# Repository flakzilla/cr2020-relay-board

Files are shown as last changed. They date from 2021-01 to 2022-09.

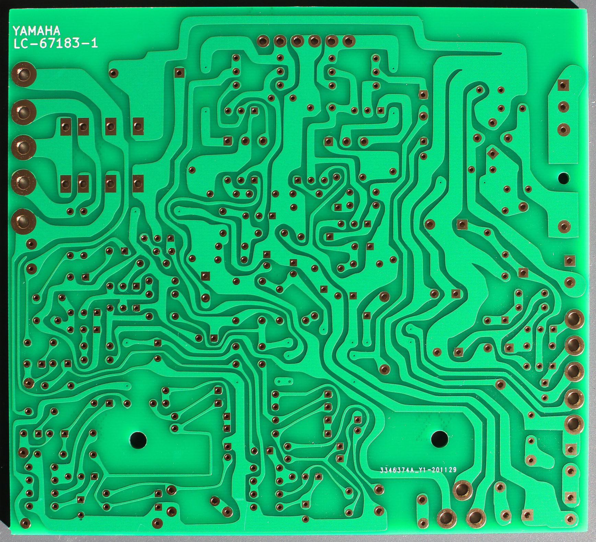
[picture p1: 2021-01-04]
img/board_rear.jpg

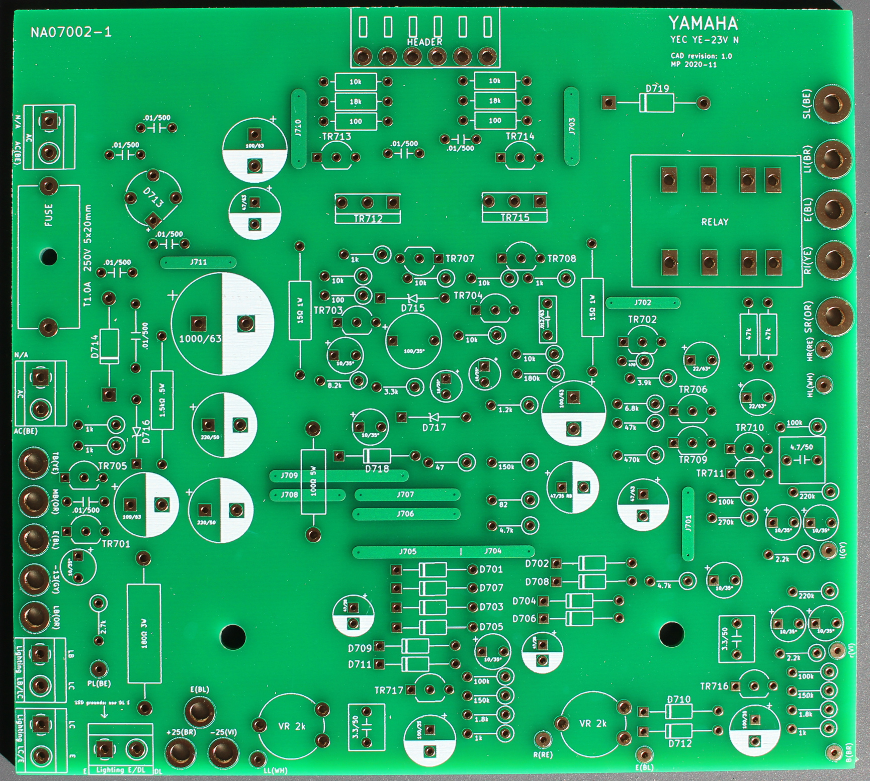
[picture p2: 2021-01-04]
img/board_front.jpg

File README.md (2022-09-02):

# Yamaha CR-2020 relay board LC-67183-1 CAD Reproduction
A modern CAD replica of the LC-67183-1 relay board from the power supply of a Yamaha CR-2020 reciever.

Finished Board

[Front Detail](img/board_front.jpg?raw=true)

[Rear Detail](img/board_rear.jpg?raw=true)

## Summary
This project faithfully recreates the original board based on a sample LC-67183-1 board from a 1976 North American market CR-2020. A complete BOM is provided, including modern part substitutions where original parts may not be available. The KiCAD project files are available for download from this repository ([direct link](https://github.com/flakzilla/cr2020-relay-board/tree/main/CR-2020%20relay%20board%20LC-67183-1)).

The replica doesn't *perfectly* recreate original board - some liberties were taken to make the design more suitable for modern components, and to make some practical changes.

AK user Jayfree also designed a replacement for the relay board, his is a modernized two-layer design instead of a reproduction of the original design. Available here: https://www.audiokarma.org/forums/index.php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 ([Photo](https://www.audiokarma.org/forums/index.php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))

Replica filter capacitor boards have been made as well:
1. [niclasf's board](https://foogadgets.blogspot.com/2020/05/yamaha-cr2020-repair.html) - to get one, contact niclasf on AK, or use his web store at https://www.facebook.com/foogadgets/
1. [jayfree's board](https://www.audiokarma.org/forums/index.php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) - ([Photo](https://www.audiokarma.org/forums/index.php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))

### Caution & Advice
* There are some small differences between model years, but as far as I can tell, this board should work for any model year. **Check your CR-2020's power supply carefully** before trying to use this reproduction board.
* At least 2oz copper is required for the PCB.
* The board's silkscreen includes very small text which isn't always clearly readable. A PDF export of the silkscreen markings is included for reference.
* Read this thread first: https://www.audiokarma.org/forums/index.php?threads/cad-new-yamaha-cr-2020-capacitor-board.912553/

### Reference information for working on a CR-2020
A collection of reference information useful for working on the CR-2020 is included in this repo. The collection contains:
* Recap BOMs for all CR-2020 PCBs
* Broken-out PCB diagrams with some corrections made for misprints and errors in the original diagrams
* Datasheets for many of the original transistors and diodes
* Service Manual and power supply service bulletins
* High resolution copies of the block diagram, schematic diagram, and wiring diagram

Most of this information can be found on the Internet already, but hopefully this collection will save time for those working on a CR-2020.

https://github.com/flakzilla/cr2020-relay-board/tree/main/CR-2020%20reference%20information

### Acknowledgements
The author would like to thank AudioKarma users avionic, niclasf, and jayfree. Owe each of you a beer or 3. :)

## How-To
### PCB
Recommend JLCPCB: https://jlcpcb.com/.

Prepared gerber files for this board: [Gerbers, v1.0](https://github.com/flakzilla/cr2020-relay-board/raw/main/CR-2020%20relay%20board%20LC-67183-1/gerber%20zips/CR2020%20relay%20board%20LC-67183-1%20v1.0.zip)

Board requires 1.6mm PCB thickness and **2oz copper weight**. Thicker copper is mandatory due to high current passing through the relay.

### Parts
BOM:
* [ODS Format](https://github.com/flakzilla/cr2020-relay-board/raw/main/CR-2020%20relay%20board%20LC-67183-1/BOM/BOM.ods)
* [Excel Format](https://github.com/flakzilla/cr2020-relay-board/raw/main/CR-2020%20relay%20board%20LC-67183-1/BOM/BOM.xlsx)

Carefully read and understand the notes in the BOM sheet, and check everything against your own CR-2020. Plan to recover and reuse the factory TO-92 transistors. Note that this BOM is not compatible with Jayfree's modernized relay board (see the Summary section above).

### Assembly
Reference materials:
* [Board diagram](https://github.com/flakzilla/cr2020-relay-board/blob/main/CR-2020%20relay%20board%20LC-67183-1/reference/power%20supply%20c%20board%20diagram_fixed.png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) from the service manual, typos and mistakes present in the original diagram have been fixed
* [PDF of PCB markings](https://github.com/flakzilla/cr2020-relay-board/blob/main/CR-2020%20relay%20board%20LC-67183-1/reference/markings%20diagram%20v1.0.pdf) since the silkscreen text on the board might be too small to read clearly
* [Some examples of TO-220 heatsinks](https://github.com/flakzilla/cr2020-relay-board/tree/main/CR-2020%20relay%20board%20LC-67183-1/reference/TO-220%20heatsink) that can be used for TR712/715

## License
This project is released under the terms of the Creative Commons Attribution + Noncommercial + ShareAlike (BY-NC-SA) license. https://creativecommons.org/licenses/by-nc-sa/2.0/

This project is distributed 'as-is' in the hope that it will be useful, but WITHOUT ANY WARRANTY; without even the implied warranty of MERCHANTABILITY or FITNESS FOR A PARTICULAR PURPOSE.

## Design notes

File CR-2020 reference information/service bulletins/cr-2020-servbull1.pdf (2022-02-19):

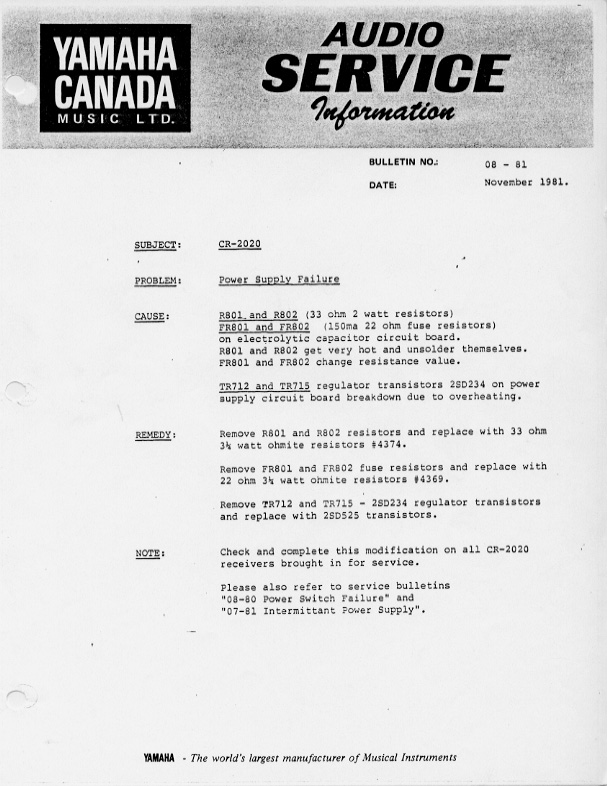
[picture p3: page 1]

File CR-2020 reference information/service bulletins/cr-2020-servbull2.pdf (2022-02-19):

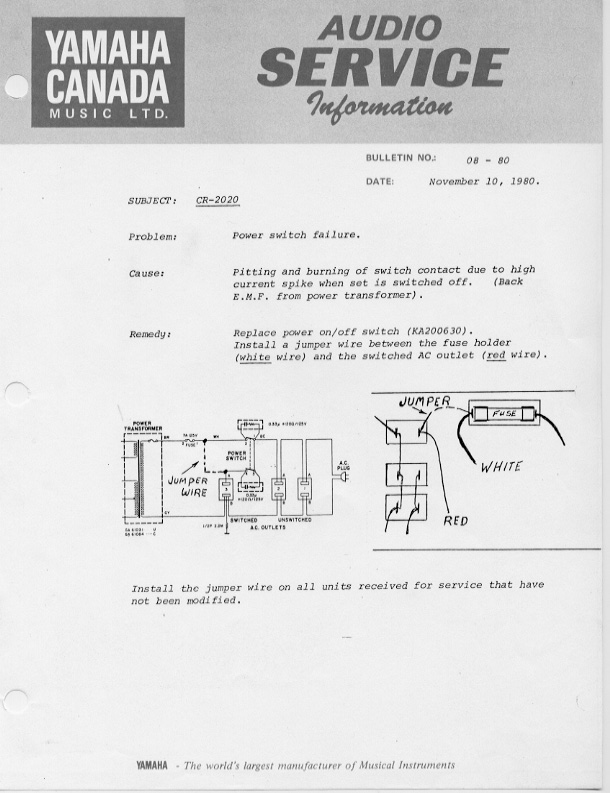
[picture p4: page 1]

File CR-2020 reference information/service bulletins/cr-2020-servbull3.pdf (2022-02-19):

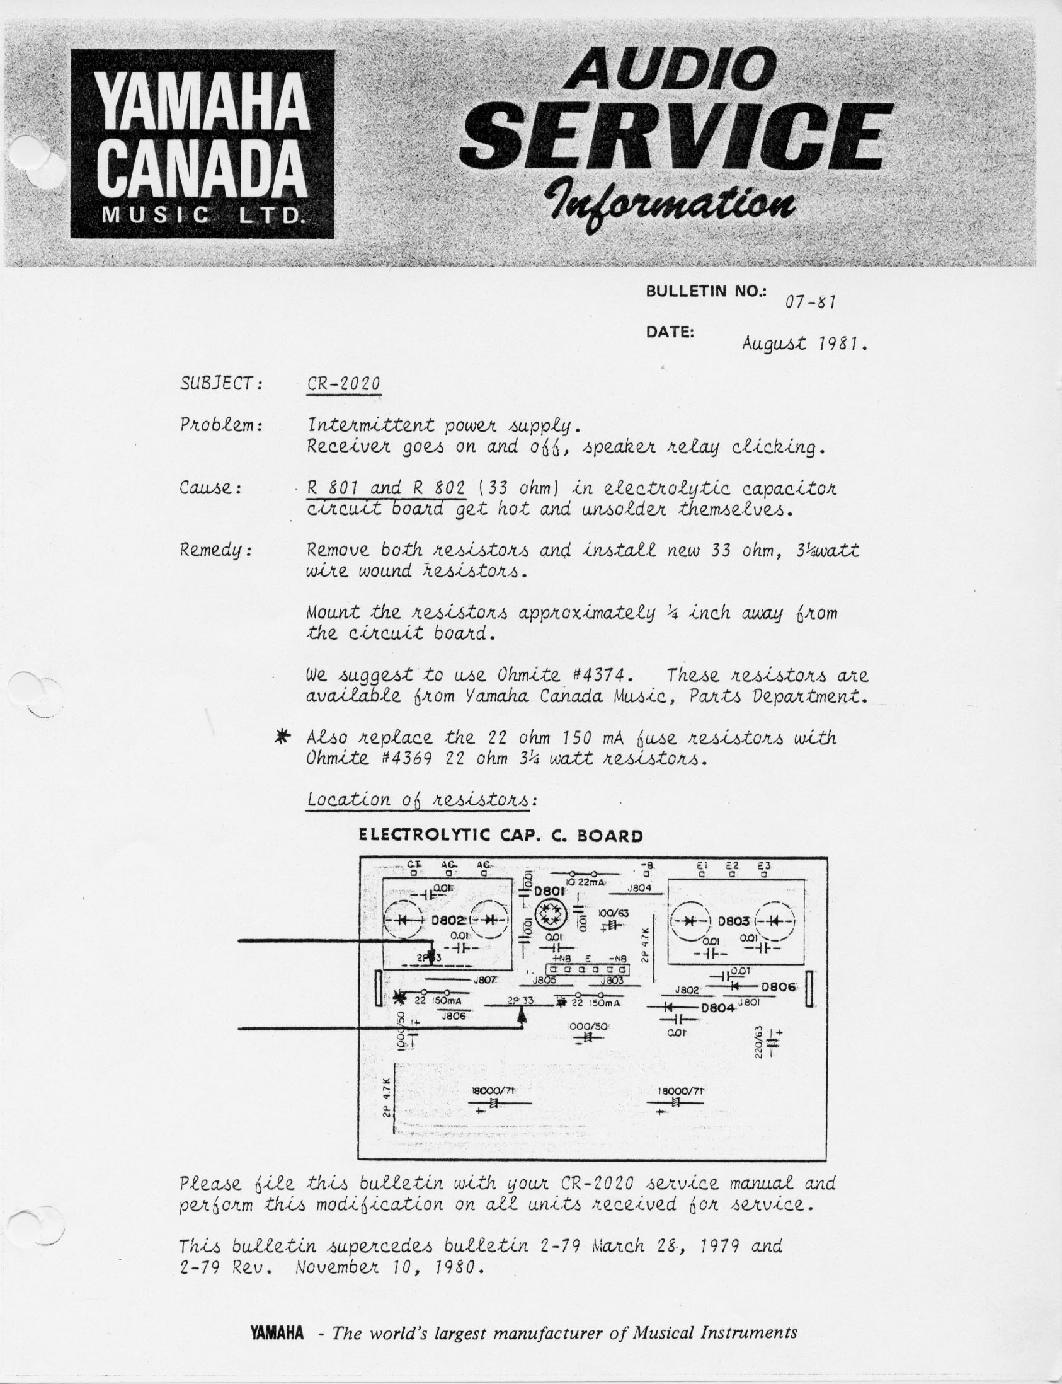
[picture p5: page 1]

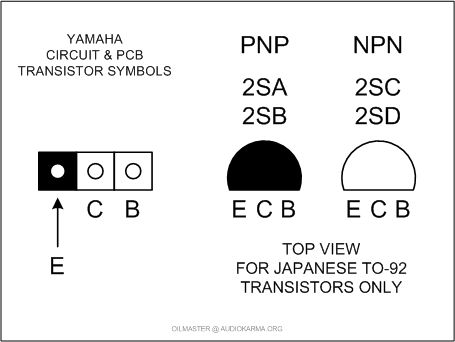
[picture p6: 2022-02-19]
CR-2020 reference information/misc/Yamaha Transistor Symbols.jpg

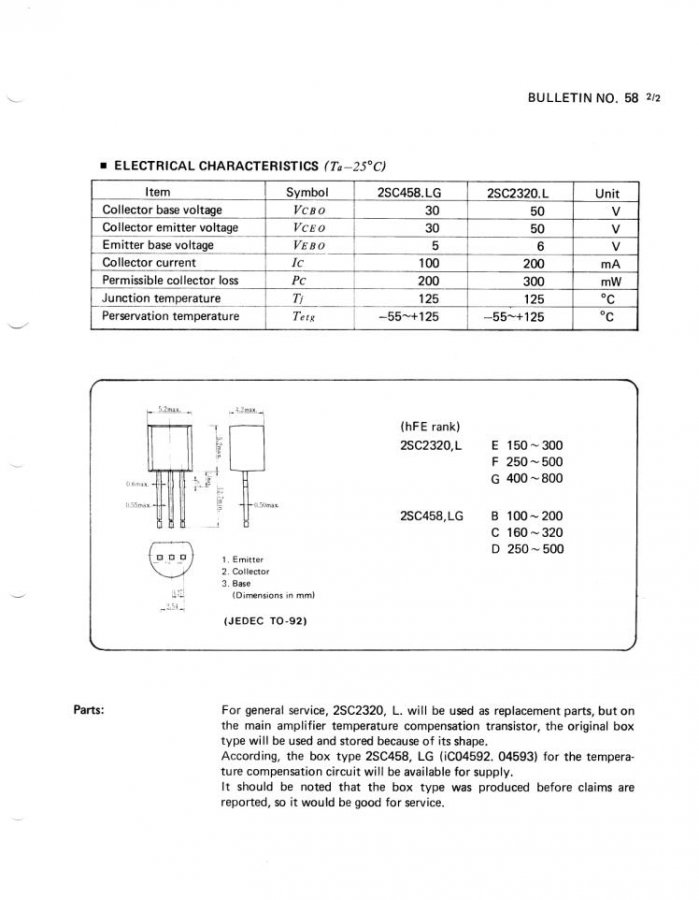
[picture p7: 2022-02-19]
CR-2020 reference information/service bulletins/2SC458-page-02_2.JPG

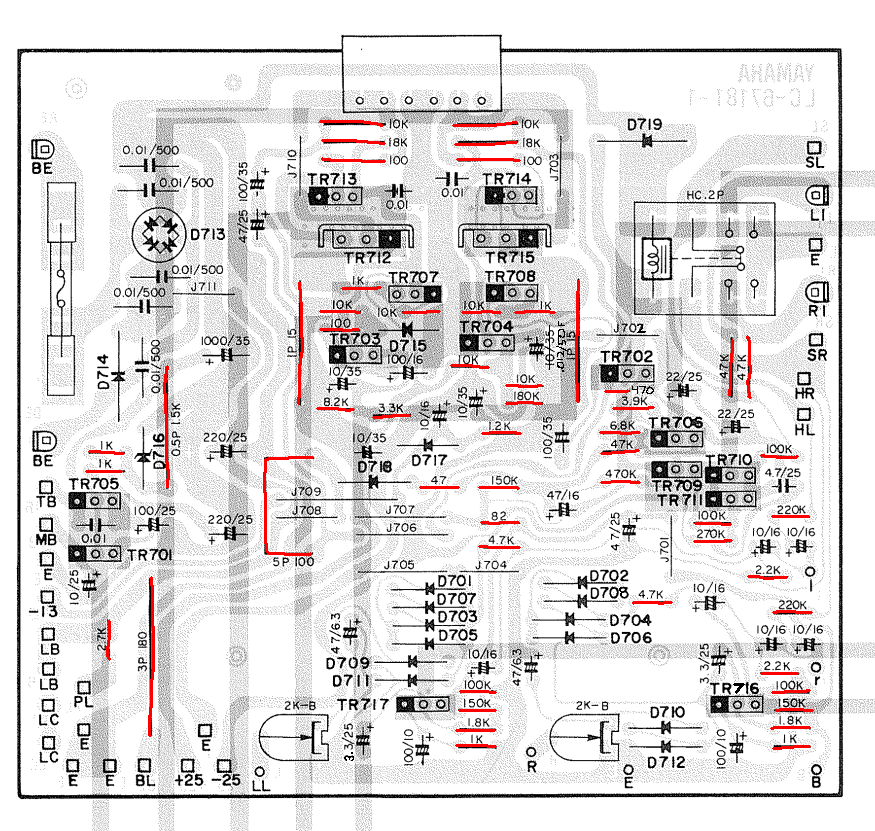
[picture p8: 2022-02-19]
CR-2020 reference information/board diagrams/power supply c board resistor map.png

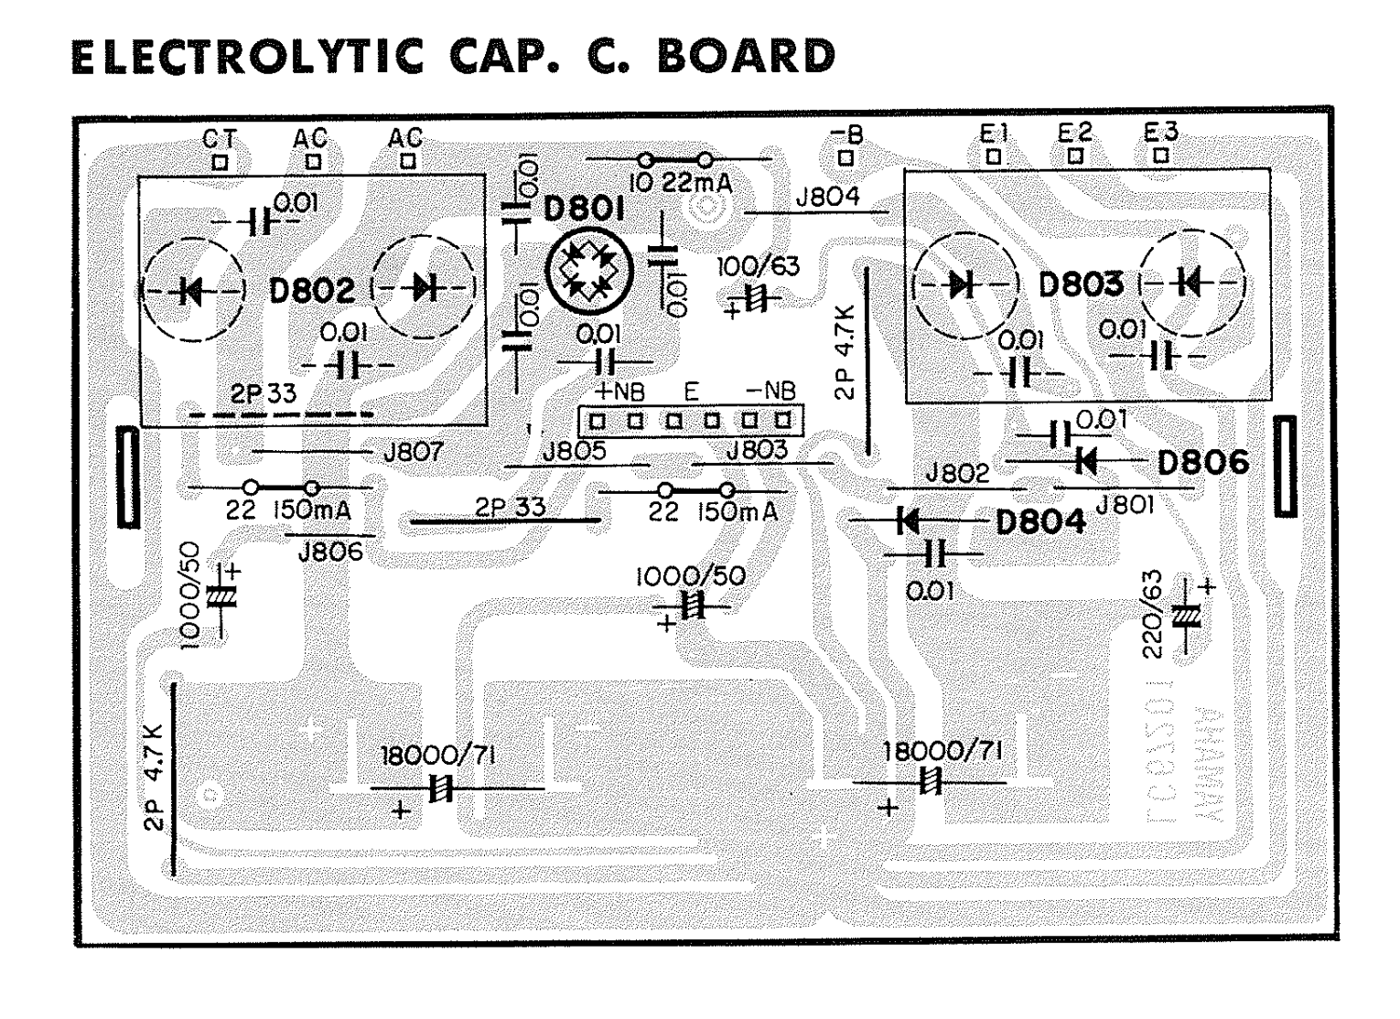
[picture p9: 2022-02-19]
CR-2020 reference information/board diagrams/electrolytic cap c board diagram.png

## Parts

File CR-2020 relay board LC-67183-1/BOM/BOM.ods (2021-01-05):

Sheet: Transistors
Transistor ID | Orig Part | Modern Sub | Remark
TR701 | 2SD400 (E) | KSC2383 (O)
TR702 | 2SB544 (E) | KSA1013 (Y)
TR703 | 2SD667 (C) | KSC2383Y or KSC2690AY | 2SD667 was installed in my 2020, service manual calls for 2SC1890. YMMV
TR704 | 2SA844 (E) | KSA1015 (Y)
TR705 | 2SD400 (E) | KSC2383 (O)
TR706 | 2SC1918 | KSC1845 | Orig part outperforms modern sub. Decent alternative is 2SC2240, if you can get one
TR707 | 2SC1213A | KSC2383 (O)
TR708 | 2SA673A | KSA1013 (Y)
TR709 | 2SC1918 | KSC1845 | Orig part outperforms modern sub. Decent alternative is 2SC2240, if you can get one
TR710 | 2SC1918 | KSC1845 | Orig part outperforms modern sub. Decent alternative is 2SC2240, if you can get one
TR711 | 2SA844 | KSA1015 (Y)
TR712 | 2SD525 | TIP41C | Original part 2SD234, service bulletin upgrades to 2SD525. If original 2SD234 is installed, replace with modern part.
TR713 | 2SD667 (C) | KSC2383Y or KSC2690AY | 2SD667 was installed in my 2020, service manual calls for 2SC1890. YMMV
TR714 | 2SA844 (E) | KSA1015 (Y)
TR715 | 2SD525 | TIP41C | Original part 2SD234, service bulletin upgrades to 2SD525. If original 2SD234 is installed, replace with modern part.
TR716 | 2SC1918 | KSC1845 | Mislabeled as “TR718” in the circuit diagram and as “TR416” on the board diagram. Orig part outperforms modern sub. Decent alternative is 2SC2240, if you can get one
TR717 | 2SC1918 | KSC1845 | Orig part outperforms modern sub. Decent alternative is 2SC2240, if you can get one

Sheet: Capacitors
Capacitor Type | uF | V | Dia | Lead spacing | Qty | Modern replacement | Remark
Ceramic disc | 0.01 | 630 | 5mm | 5mm (and one 10mm) | 8 | TDK FA26C0G2J103JNU06 | Modern repl is MLCC type with C0G dielectric
Film | 3.3 | 50 | 7.2x5.5 | 5mm | 2 | MKS2B043301H00JSSD | Original low-uF electrolytic replaced with film
Film | 4.7 | 50 | 7.2x5.5 | 5mm | 1 | MKS2B044701K00JSSD | Original low-uF electrolytic replaced with film
Film | 0.012 | 63 | 7.2x2.5 | 5mm | 1 | MMK5123J63J01L16.5TA18 | This is the factory sub part between TR704 and TR702
Electrolytic (RB type) | 47 | 35 | 8mm | 3.5mm | 1 | UKL1V470KPDANA | This is the “RB Type” 47/16 capacitor above D702, replace with low leakage type
Electrolytic | 100 | 63 | 10mm | 5mm | 3 | UPW1J101MPD
Electrolytic | 47 | 63 | 8mm | 3.5mm | 2 | UPW1J470MPD
Electrolytic | 1000 | 63 | 16mm | 7.5mm | 1 | UPW1J102MHD
Electrolytic | 220 | 50 | 10mm | 5mm | 2 | UPW1H221MPD
Electrolytic | 10 | 35 | 5mm | 2mm | 11 | UPW1V100MDD | Footprint may be deliberately enlarged for better pad placement – marked with *
Electrolytic | 100 | 35 | 8mm | 3.5mm | 3 | UPW1V101MPD | Footprint may be deliberately enlarged for better pad placement – marked with *
Electrolytic | 47 | 35 | 6.3mm | 2.5mm | 2 | UPW1V470MED
Electrolytic | 22 | 63 | 6.3mm | 2.5mm | 2 | UPW1J220MED | Footprint may be deliberately enlarged for better pad placement – marked with *

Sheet: Diodes
Diode ID | Type | Qty | Lead spacing | Orig. Spec | Modern replacement | Modern replacement (alt) | Remark
D701-712,718 | Diode DO-35 | 13 | Variable | 1S1555 | 1N4148
D714 | Diode DO-41 | 1 | Variable | 1S1885 | 1N4002G
D715 | Zener DO-35 | 1 | Variable | HZ78 | TZX6V8D
D716-717 | Zener DO-35 | 2 | Variable | HZ12C | NZX14A,133
D719 | Diode DO-41 | 1 | Variable | 1S1886 | 1N4004G |  | 1S1886 was installed in my CR, service manual calls for 1S1555. YMMV
D713 | Bridge Rectifier WOM-4 | 1 | 5mm | 1D4B1 (1.5A / 200v) | Rectron W04M | Vishay B250C1500G-E4/51 | Rectron part is EOL, but may still be available

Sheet: Resistors
Type | Resistance | Power | Qty | Modern replacement | Modern replacement (alt) | Resistance of new part (if different from original) | Remark
Power (WW) | 15 | 1 | 2 | Vishay RS01A15R00FB12
Power (WW) | 180 | 3 | 1 | Vishay RS02B180R0FE12
Power (WW) | 100 | 5 | 1 | Ohmite WHE100FET | Vishay RS005100R0FB12 |  | Pad spacing is narrow for a 5W WW resistor. Ohmite part is 5mm shorter and is easier to fit, but either works. Leads must be formed to make a standoff
Power (MOX) | 1.5k | 0.5 | 1 | CMF601K5000BEBF
MOX | 10k | 0.25 | 7 | CMF5510K000FKEB
MOX | 18k | 0.25 | 2 | CMF5518K200FKEK |  | 18.2k
MOX | 100 | 0.25 | 3 | CMF55100R00FHEK
MOX | 47k | 0.25 | 3 | CMF5547K000FHEK
MOX | 1k | 0.25 | 4 | CMF551K0000FHEB
MOX | 1k | 0.25 | 2 | CMF501K0000FHEB |  |  | Use these two for the two groups of 4 near the front, .25W part can sit flush with board
MOX | 2.7k | 0.25 | 1 | CMF552K7000FKR6
MOX | 100k | 0.25 | 2 | CMF55100K00FHEA
MOX | 100k | 0.25 | 2 | CMF50100K00FHEB |  |  | Use these two for the two groups of 4 near the front, .25W part can sit flush with board
MOX | 150k | 0.25 | 1 | CMF55150K00FKEA
MOX | 150k | 0.25 | 2 | CMF50150K00FHEB |  |  | Use these two for the two groups of 4 near the front, .25W part can sit flush with board
MOX | 1.8k | 0.25 | 2 | CMF501K8200FHEB |  | 1.82k | Use these two for the two groups of 4 near the front, .25W part can sit flush with board
MOX | 2.2k | 0.25 | 2 | CMF552K2000FKEK
MOX | 220k | 0.25 | 2 | CMF55221K00FHEK |  | 221k
MOX | 4.7k | 0.25 | 2 | CMF554K7000FHEK
MOX | 270k | 0.25 | 1 | CMF55274K00FHEB |  | 274k
MOX | 470 | 0.25 | 1 | CMF55470R00FKR6
MOX | 3.9k | 0.25 | 1 | CMF553K9000FKBF
MOX | 6.8k | 0.25 | 1 | CMF556K8000FKEB
MOX | 470k | 0.25 | 1 | CMF55475K00FHEA |  | 475k
MOX | 47 | 0.25 | 1 | CMF5547R000FEEK
MOX | 82 | 0.25 | 1 | H882RFZA
MOX | 180k | 0.25 | 1 | CMF55182K00FKEK |  | 182k
MOX | 1.2k | 0.25 | 1 | CMF551K2000FKR6
MOX | 8.2k | 0.25 | 1 | CMF558K2500FKEK |  | 8.25k
MOX | 3.3k | 0.25 | 1 | CMF553K3200FHEB |  | 3.32k
Trim pot | 2k | ?? | 2 | PT10LV10-202A2020-PM-S |  |  | Thanks jayfree :)

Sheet: Misc
Part | Orig. Spec | Qty | Modern replacement | Remark
Fuse holder | 6x30mm type fuse holder | 1 | Schurter 0031.8201
Fuse | 6x30mm 1A 250V fast blow | 1 | Littelfuse 0217001.MXP | Any standard 5x20mm 1A fast-blow fuse will work fine
Protection relay | Panasonic HC2-HP-DC12V-F | 1 | Omron MY2-02-DC12 | Orig part has wider mounting pins (1.5mm)
6-pin header |  | 1 | Molex 09-48-3065
1x2 Terminal block | wire wrap pin/solder tab | 5 | Phoenix 1729128 | 1x2, 5.08mm pitch
Large turret | wire wrap pin/solder tab | 13 | Mill-Max 2801-3-00-80-00-00-07-0 | Intended for swage mount, but can be soldered
Small turret | wire wrap pin | 9 | Mill-Max 6821-0-00-01-00-00-08-0
TO-220 Heatsink Option 1 |  |  |  | Larger heatsink, but it needs to be cut down with a hacksaw
TO-220 Heatsink (main) | Aluminum extrusion, 10Dx36Hx18W mm | 2 | Ohmite WA-T220-101E | Cut off the bottom part of the rear fins so that heatsink will fit without hitting TR713/714, cut off middle fin, drill 1/8” hole at the correct spot for mounting the transistor. See reference photos
TO-220 Heatsink (extension) |  | 2 | CUI HSS-B20-NP-10 | To install extension: drill a second 1/8” hole above transistor mounting hole and matching hole thru extension. Mount extension to main heat sink with the second screw
TO-220 Heatsink mounting screw |  | 2 | Keystone 4690
TO-220 Heatsink nut |  | 2 | Keystone 4694
TO-220 Heatsink Option 2 |  |  |  | Smaller heatsink but can be put together with no modification
TO-220 Heatsink (main) | Aluminum extrusion, 10Dx36Hx18W mm | 2 | CUI HSE-B2111-038
TO-220 Heatsink (extension) |  | 2 | CUI HSS-B20-NP-10 | To install extension: drill a 1/8” hole through the back, and sandwich it with thermal compound upside-down against the back of the main heatsink, secured by transistor mounting screw. See reference photos
TO-220 Heatsink mounting screw |  | 2 | Keystone 4690
TO-220 Heatsink lock washer |  | 2 | Keystone 4700
TO-220 Heatsink nut |  | 2 | Keystone 4694

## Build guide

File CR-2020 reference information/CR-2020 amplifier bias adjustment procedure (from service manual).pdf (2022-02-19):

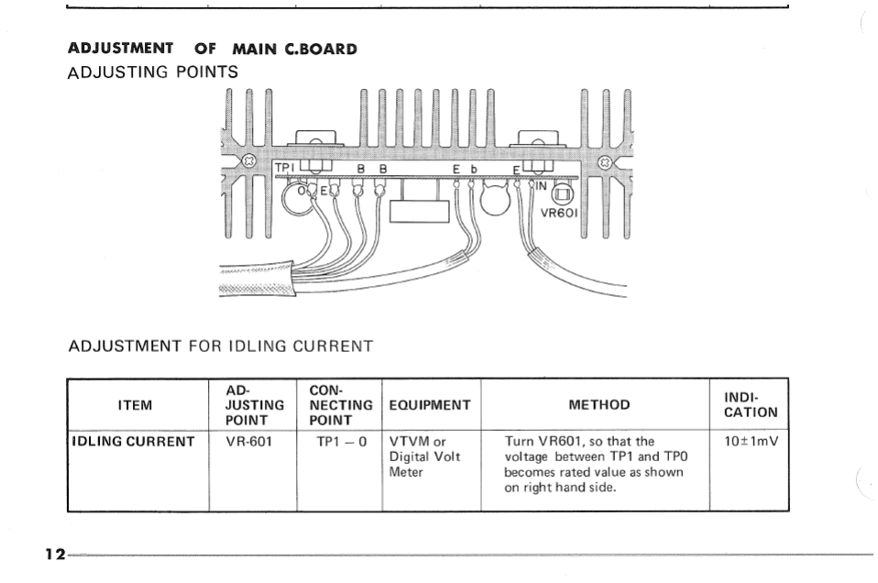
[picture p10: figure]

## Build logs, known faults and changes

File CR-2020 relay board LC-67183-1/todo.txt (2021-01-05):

- increase text size for silkscreen
- increase TR712/715 pad size for better physical strength
- fix hole in rear trace footprint under 100/35 near D710/D712
- orient vertical text to the right, so it's pointed the right way to be legible when board is installed
- Add markings for NB+/-

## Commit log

2021-01-05 kicad files for v1.0
    [BOM.ods, BOM.xlsx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]
2022-02-19 reference information for working on a CR-2020
    [main c board capacitors.ods, pre c boards capacitors.ods, relay board capacitors.ods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]
